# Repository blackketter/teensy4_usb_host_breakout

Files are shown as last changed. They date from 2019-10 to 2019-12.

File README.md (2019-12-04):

A companion breakout board with USB-A host connector to mate with the [Teensy 4 Header Breakout Board](https://github.com/blackketter/teensy4_header_breakout).  

It's designed to solder to the top 6 pins on the right side of the Teensy 4 Header Breakout.  

Designed in KiCad.

Notes:

- See also [Combo SD/USB Host breakout](https://github.com/blackketter/teensy4_combo_breakout)
- In progress: First prototype works great.
- With longer header pins you should be able to flip the board to be under or over the Teensy 4.0
- Download bom/ibom.html and view it with web browser to see bill of materials and placement information.
- The 6th pin provides an optional enable pin for the power management chip on digital pin 27.  For always-on, cut left trace and short right two pads.  

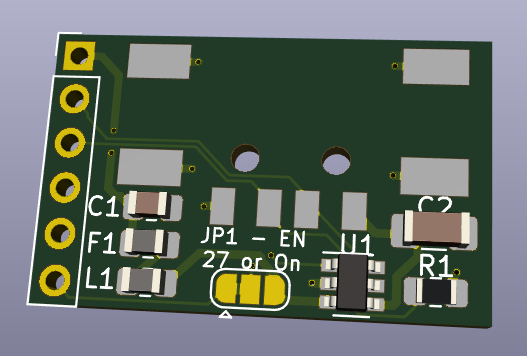
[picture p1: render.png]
breakout render

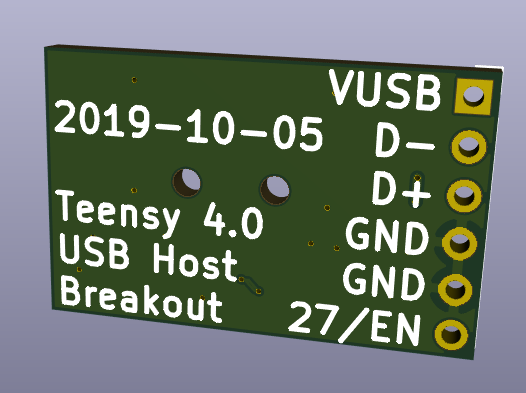
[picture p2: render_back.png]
breakout render_back


Pinout:

1. VUSB
2. USB Host D-
3. USB Host D+
4. GND
5. GND
6. 27/EN

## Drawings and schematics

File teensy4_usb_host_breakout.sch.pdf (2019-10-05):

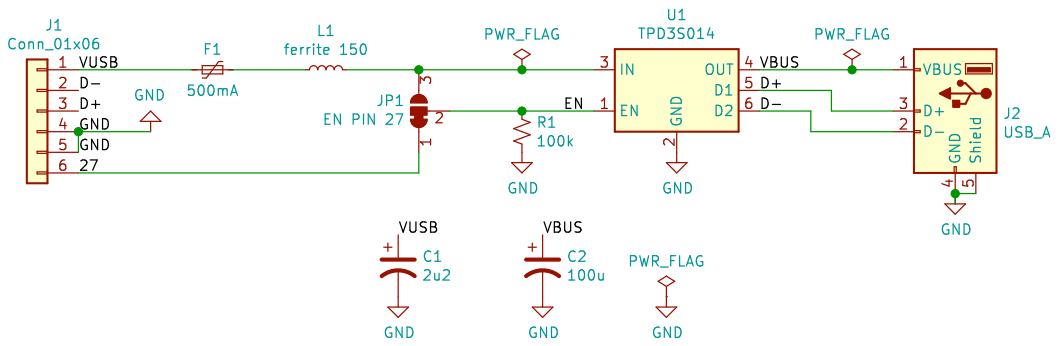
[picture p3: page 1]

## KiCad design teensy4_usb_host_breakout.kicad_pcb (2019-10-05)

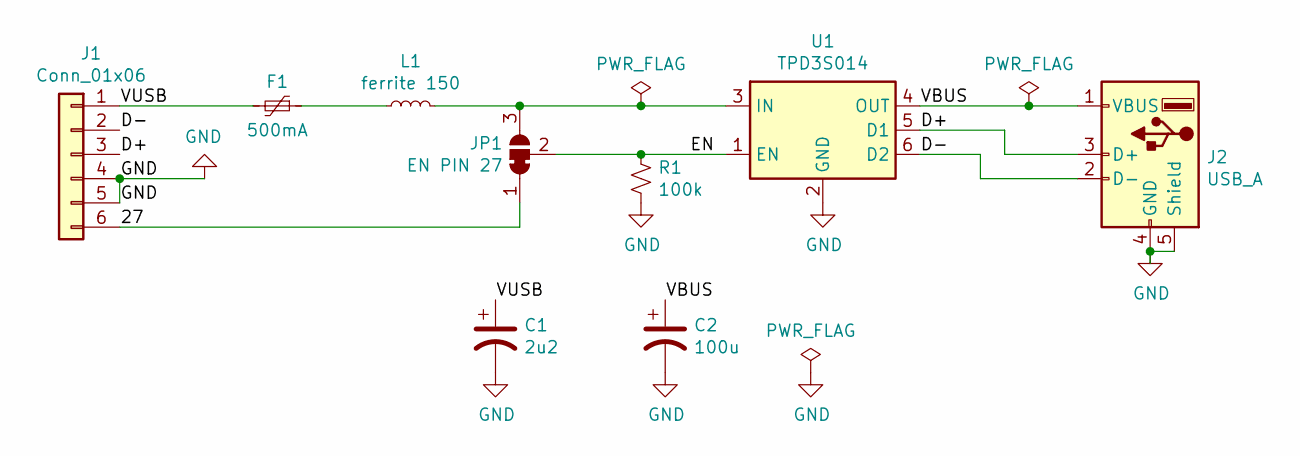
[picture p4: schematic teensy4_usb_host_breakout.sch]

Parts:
C1: 2u2; C_0805_2012Metric_Pad1.15x1.40mm_HandSolder; Digikey 1276-1188-1-ND
C2: 100u; C_1206_3216Metric_Pad1.42x1.75mm_HandSolder; Digikey ‎478-12404-1-ND‎
F1: 500mA; L_0805_2012Metric_Pad1.15x1.40mm_HandSolder; Digikey 507-1813-1-ND
J1: Conn_01x06; PinHeader_1x06_P2.54mm_Vertical
J2: USB_A; USB_A_Receptacle_SMD_Wuerth_629104190121; Digikey 732-11179-1-ND
JP1: EN PIN 27; SolderJumper-3_P1.3mm_Bridged12_RoundedPad1.0x1.5mm
L1: ferrite 150; L_0805_2012Metric_Pad1.15x1.40mm_HandSolder; Digikey ‎490-1038-1-ND‎
R1: 100k; R_0805_2012Metric_Pad1.15x1.40mm_HandSolder; Digikey 311-100KCRCT-ND
U1: TPD3S014; SOT-23-6; Digikey 296-38835-1-ND

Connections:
/27: J1.6, JP1.1 (A)
/D+: J1.3, J2.3 (D+), U1.5 (D1)
/D-: J1.2, J2.2 (D-), U1.6 (D2)
/EN: JP1.2 (C), R1.1, U1.1 (EN)
/VBUS: C2.1, J2.1 (VBUS), U1.4 (OUT)
/VUSB: C1.1, F1.2, J1.1
GND: C1.2, C2.2, J1.4, J1.5, J2.4 (GND), J2.5 (Shield), R1.2, U1.2 (GND)
unnamed: F1.1, L1.1
unnamed: JP1.3 (B), L1.2, U1.3 (IN)

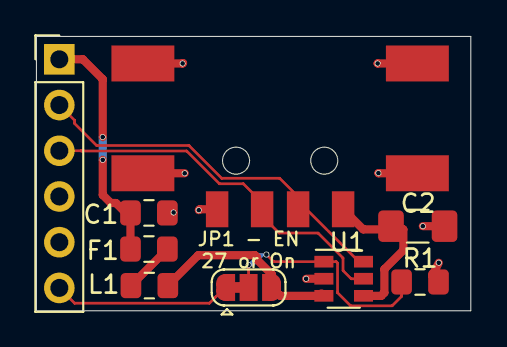
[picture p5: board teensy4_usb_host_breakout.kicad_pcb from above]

Board: 2 copper layers, 24.1 x 15.2 mm, 9 parts (0 on the bottom side), 9 nets.

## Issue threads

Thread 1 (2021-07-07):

advantage to micro-USB-to-USB adapter

banannakn, 2021-07-07:
Thanks for the nice usb_host_breakout, but I am not sure whether I understood the advantage correctly.
I want to communicate to an embedded system with my Teensy 4.0. The communication protocol is UART but the plug is USB which I want to connect to the Teensy 4.0. The cable comes with an USB Full Speed to Serial UART IC. Why can't I just use a micro-USB-to-USB adapter to connect to the already set up micro-USB port? Or is the advantage with the usb_host_breakout that I am able to communicate via USB while connecting the Teensy to the computer via micro-USB for debugging purpose? Can I then use (with the usb_host_breakout) the USB port and micro-USB port simultaneously?

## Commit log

2019-09-21 Widened VIN power trace
    [teensy4_usb_host_breakout.kicad_pcb]
2019-09-21 Update footprintso
    [teensy4_usb_host_breakout.kicad_pcb, teensy4_usb_host_breakout.sch]
2019-09-22 Update status
    [teensy4_usb_host_breakout.kicad_pcb]
2019-09-22 Updated with Digikey part numbers. Removed diodes as TPD3S014DBVR provides reverse voltage protection
    [teensy4_usb_host_breakout.kicad_pcb, teensy4_usb_host_breakout.sch]
2019-09-22 Remove spurious silkscreen lines, update render
    [teensy4_usb_host_breakout.kicad_pcb]
2019-09-22 Update schematic PDF
2019-10-05 Updated for jumper for enable (always on vs 27). Also updated docs
    [teensy4_usb_host_breakout.kicad_pcb, teensy4_usb_host_breakout.sch]
